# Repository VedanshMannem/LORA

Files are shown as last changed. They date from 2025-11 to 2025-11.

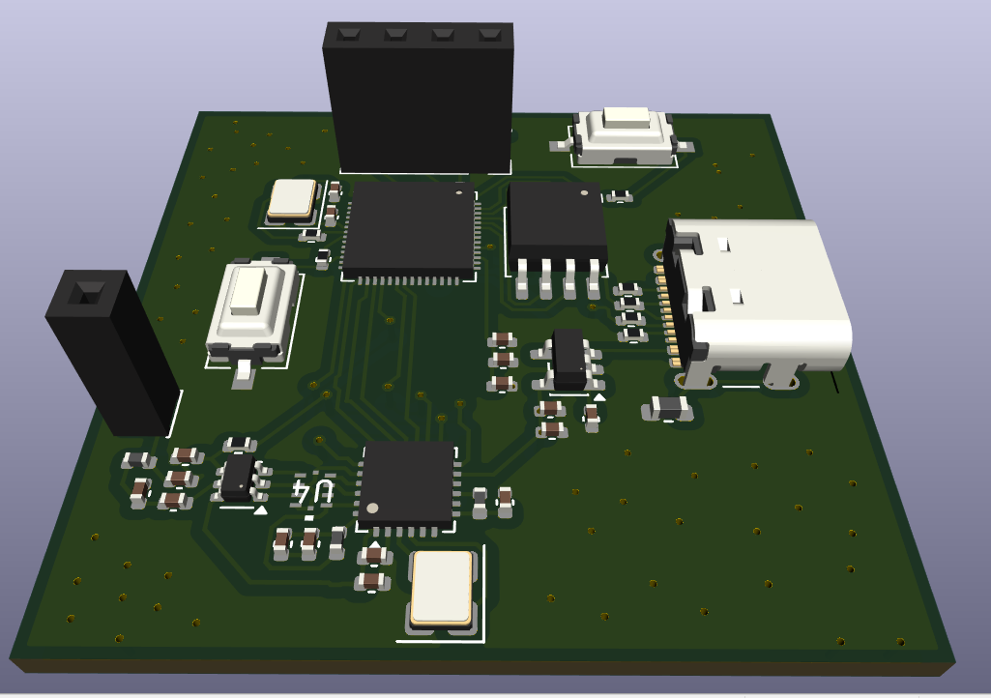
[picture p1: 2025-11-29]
photos/Screenshot 2025-11-29 044827.png

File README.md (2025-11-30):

# LoRa puck
This project's goal is to make my own LoRa (long rage) puck. It can transmit RF (radio frequency) signals and this board also comes with a 4 pin connector to attach outside sensors. The ultimate purpose of this board is to learn more about RF circuits and logic as well as create a module for transmission. 

## Some takeaways
This is one of my first full scale PCB projects. I found this one extremely fun because I got to learn a lot more about RF circuits, some of the physics behind managing these electronics, and it was just great practice overall to improve my schematics and PCB routing. This was also my first time working with multi-layer PCBs, and the whole via concept was really cool to connect gnd across different layers. Until now, this has definitely been my best hardware project!

## Usage
This repo contains KiCAD project files as well as photos showing the finished project (schematics, 2D & 3D layout JLCPCB final version, etc.). The included BOM contains a full cost breakdown of all necessary components. Some components aren't in stock currently, so a few subsitutes were used. A lot of them also require extended assembly, slightly increasing the cost of the PCB. I have a few substitutes to my BOM already listed, but I think it's price optimized especially considering all the specific modules required for this project. 

## Some photos:




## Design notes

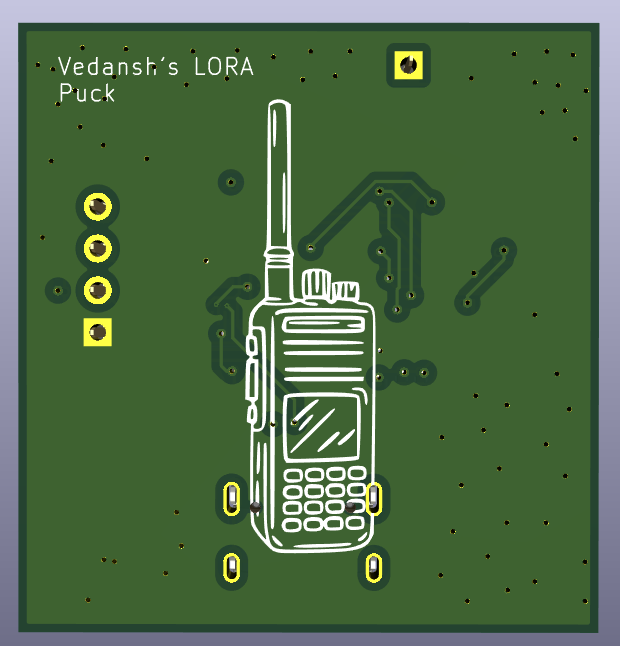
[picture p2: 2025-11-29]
photos/Screenshot 2025-11-29 053127.png

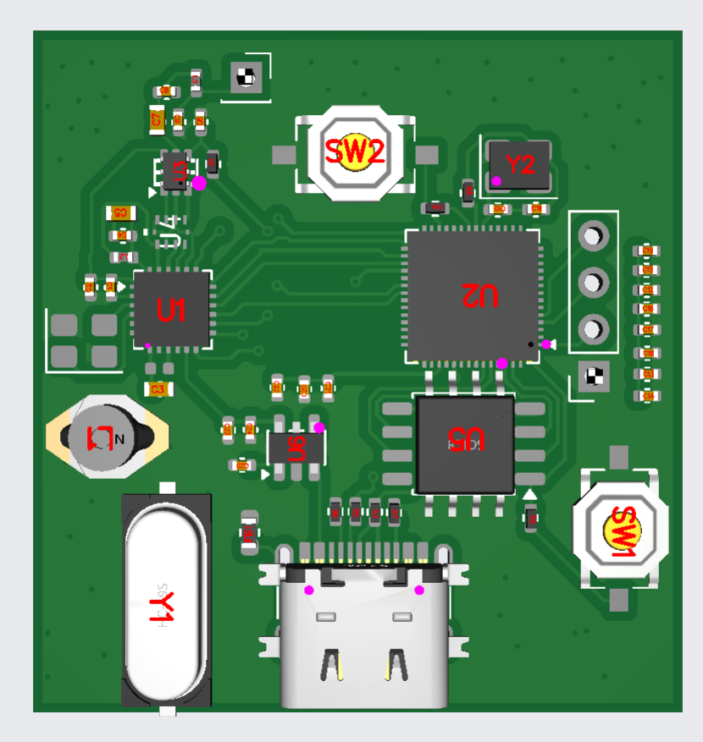
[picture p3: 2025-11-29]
photos/Screenshot 2025-11-29 154054.png

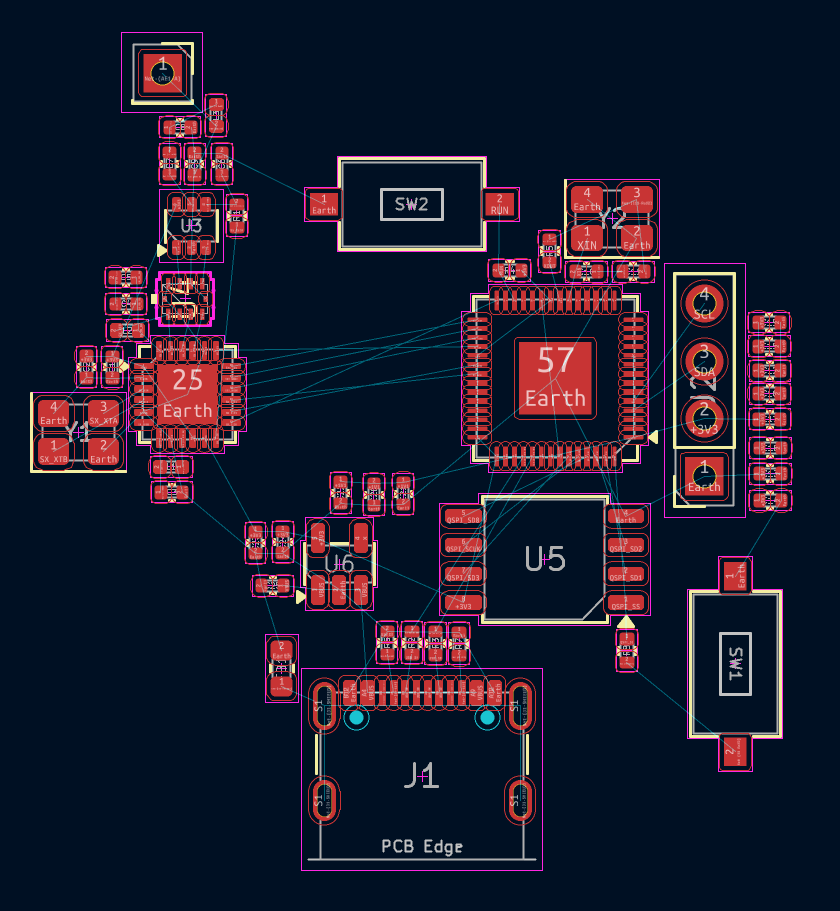
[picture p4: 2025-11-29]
photos/Screenshot 2025-11-29 034014.png

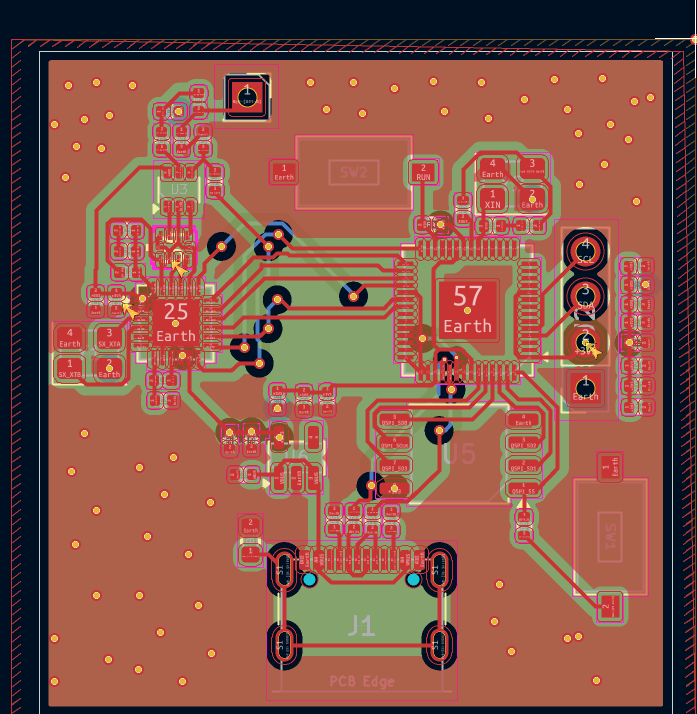
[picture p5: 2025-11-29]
photos/Screenshot 2025-11-29 044521.png

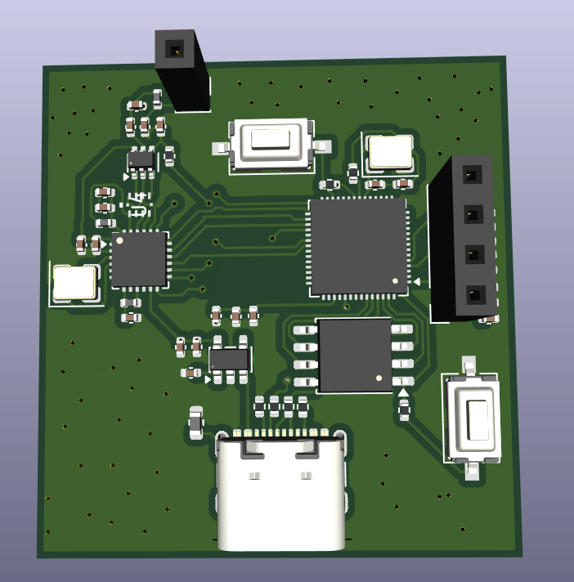
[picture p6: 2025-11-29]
photos/Screenshot 2025-11-29 045448.png

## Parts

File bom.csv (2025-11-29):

Part Number | Description | Qty | Total Price | Link
C10852 | 4*4*1.7 贴片 (Tact Switch) | 5 | 0.1035 | https://lcsc.com/search?q=C10852
C23380830 | AP2112K-3.3TRG1 | 5 | 0.4405 | https://lcsc.com/search?q=C23380830
C25744 | 0402WGF1002TCE | 2 | 0.0012 | https://lcsc.com/search?q=C25744
C1622 | CL10B473KB8NNNC | 2 | 0.0106 | https://lcsc.com/search?q=C1622
C18077642 | BX-TYPE-C-MWT16P | 7 | 1.6695 | https://lcsc.com/search?q=C18077642
C2831497 | 434MHz-SMA Flexible antenna | 2 | 3.615 | https://lcsc.com/search?q=C2831497
C9002 | X322512MSB4SI | 2 | 0.129 | https://lcsc.com/search?q=C9002
C25076 | 0402WGF1000TCE | 2 | 0.001 | https://lcsc.com/search?q=C25076
C14709 | BLM18PG121SN1D | 2 | 0.012 | https://lcsc.com/search?q=C14709
C49569550 | 2011-1X04G00LB | 2 | 0.0426 | https://lcsc.com/search?q=C49569550
C2040 | RP2040 | 2 | 1.833 | https://lcsc.com/search?q=C2040
C329840 | SDT0402T-150M-N | 5 | 1.7925 | https://lcsc.com/search?q=C329840
C131025 | W25Q16JVSSIQ | 2 | 1.11 | https://lcsc.com/search?q=C131025
C97998 | LQG15HS47NJ02D | 20 | 0.152 | https://lcsc.com/search?q=C97998
C1567 | 0402CG470J500NT | 2 | 0.002 | https://lcsc.com/search?q=C1567
C274349 | RC0402FR-0727R4L | 20 | 0.008 | https://lcsc.com/search?q=C274349
C1565 | 0402CG3R3C500NT | 20 | 0.02 | https://lcsc.com/search?q=C1565
C1623 | CL10B474KA8NNNC | 2 | 0.014 | https://lcsc.com/search?q=C1623
C15525 | CL05A106MQ5NUNC | 4 | 0.018 | https://lcsc.com/search?q=C15525
C52923 | CL05A105KA5NQNC | 4 | 0.0116 | https://lcsc.com/search?q=C52923
C12674 | X49SM8MSD2SC | 2 | 0.1704 | https://lcsc.com/search?q=C12674
C1548 | 0402CG150J500NT | 4 | 0.004 | https://lcsc.com/search?q=C1548
C11702 | 0402WGF1001TCE | 4 | 0.0024 | https://lcsc.com/search?q=C11702
C162547 | LQG15HS9N1J02D | 20 | 0.118 | https://lcsc.com/search?q=C162547
C1525 | CL05B104KO5NNNC | 24 | 0.0288 | https://lcsc.com/search?q=C1525
C25905 | 0402WGF5101TCE | 4 | 0.002 | https://lcsc.com/search?q=C25905
C1523 | 0402B102K500NT | 2 | 0.0022 | https://lcsc.com/search?q=C1523
C191341 | SX1262IMLTRT | 2 | 6.204 | https://lcsc.com/search?q=C191341
C47117600 | TPE4259-63 | 5 | 0.6805 | https://lcsc.com/search?q=C47117600
C1619 | 0603B393K500NT | 20 | 0.076 | https://lcsc.com/search?q=C1619

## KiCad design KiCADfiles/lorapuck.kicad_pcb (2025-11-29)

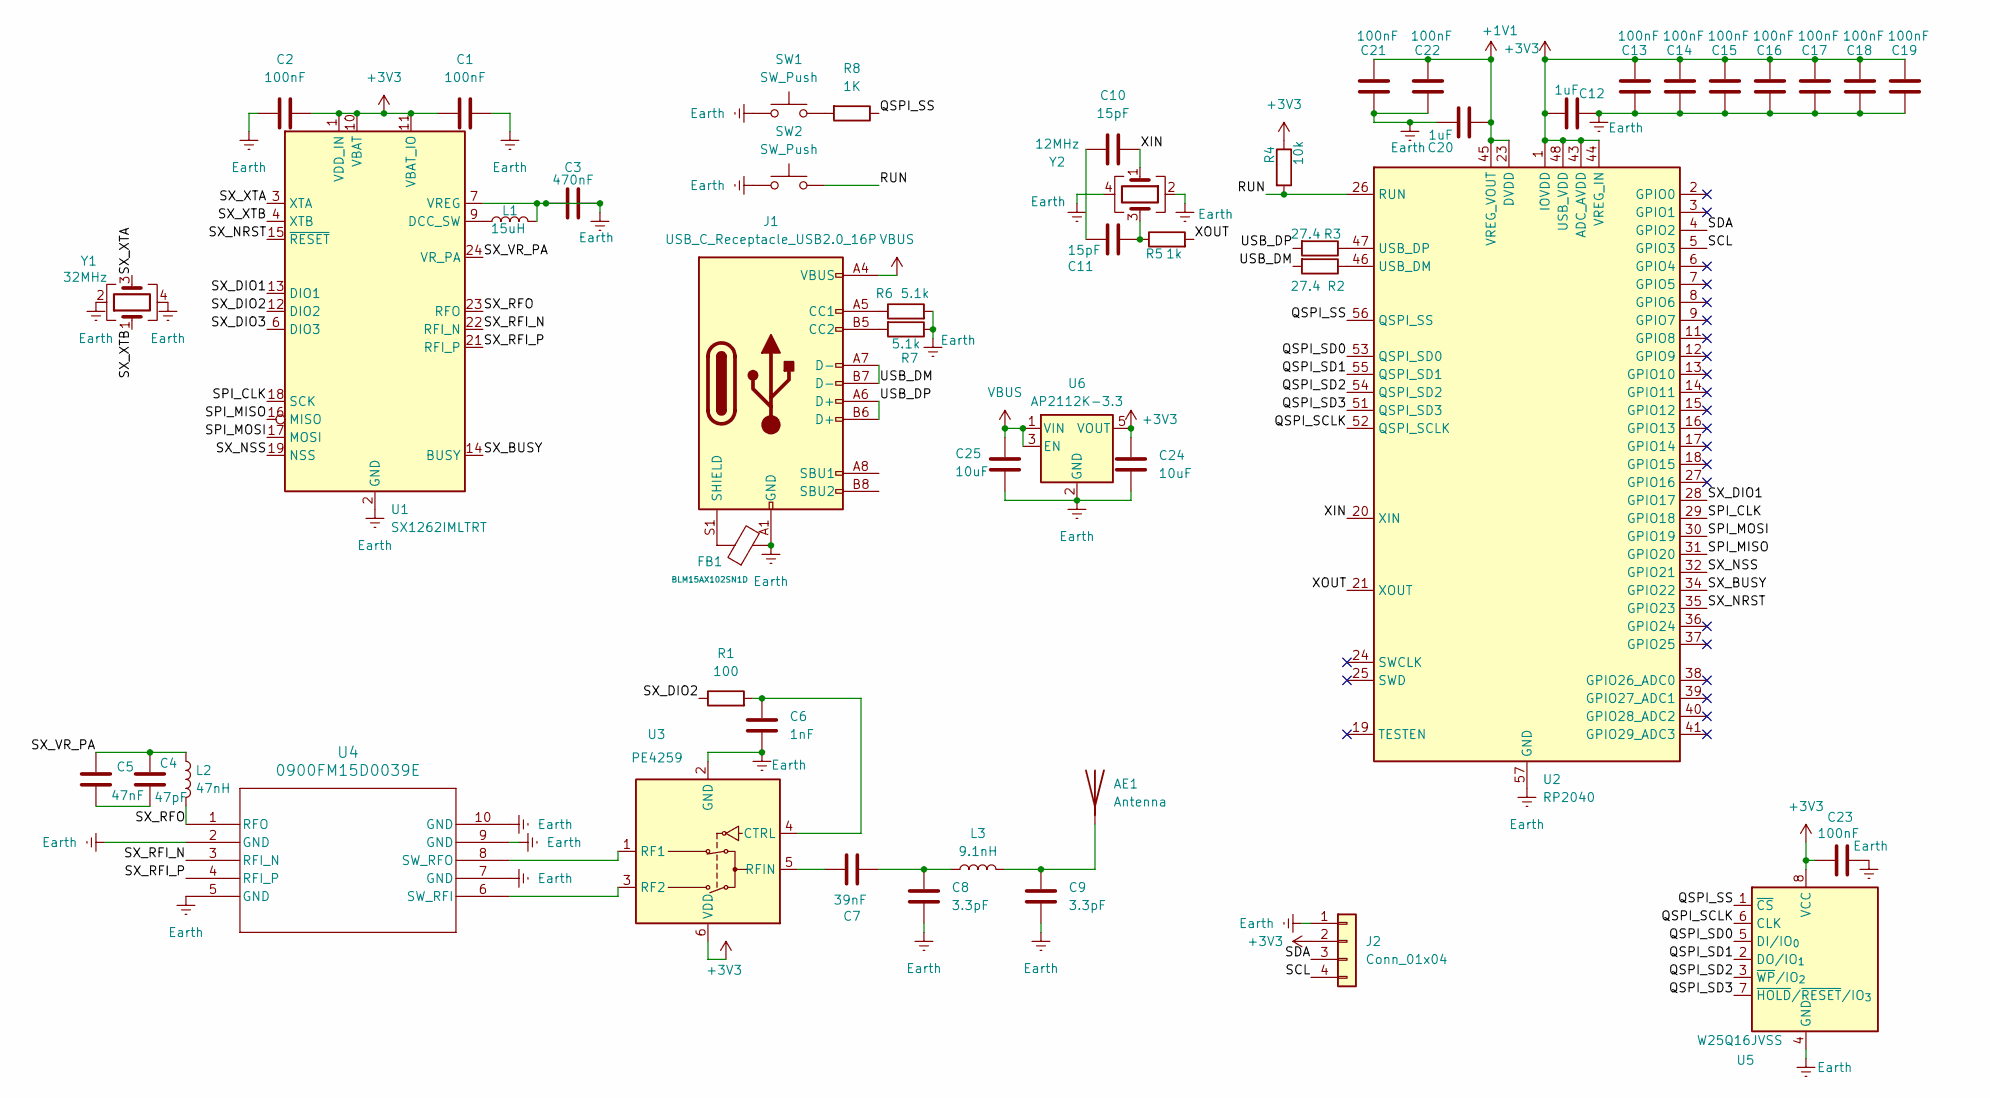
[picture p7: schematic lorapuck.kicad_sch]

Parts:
AE1: Antenna; PinSocket_1x01_P2.54mm_Vertical
C1, C2, C13, C14, C15, C16, C17, C18, C19, C21, C22, C23: 100nF; C_0402_1005Metric
C3: 470nF; C_0402_1005Metric
C4: 47pF; C_0402_1005Metric
C5: 47nF; C_0402_1005Metric
C6: 1nF; C_0402_1005Metric
C7: 39nF; C_0402_1005Metric
C8, C9: 3.3pF; C_0402_1005Metric
C10, C11: 15pF; C_0402_1005Metric
C12, C20: 1uF; C_0402_1005Metric
C24, C25: 10uF; C_0402_1005Metric
FB1: BLM15AX102SN1D; FB_0603; Current Rating 2A; Tolerance ±25%; Part BLM18PG121SN1D; LCSC C14709
J1: USB_C_Receptacle_USB2.0_16P; USB_C_Receptacle_GCT_USB4105-xx-A_16P_TopMnt_Horizontal
J2: Conn_01x04; PinSocket_1x04_P2.54mm_Vertical
L1: 15uH; L_0402_1005Metric
L2: 47nH; L_0402_1005Metric
L3: 9.1nH; L_0402_1005Metric
R1: 100; R_0402_1005Metric
R2, R3: 27.4; R_0402_1005Metric
R4: 10k; R_0402_1005Metric
R5: 1k; R_0402_1005Metric
R6, R7: 5.1k; R_0402_1005Metric
R8: 1K; R_0402_1005Metric
SW1, SW2: SW_Push; SW_Tactile_SPST_NO_Straight_CK_PTS636Sx25SMTRLFS
U1: SX1262IMLTRT; QFN-24-1EP_4x4mm_P0.5mm_EP2.6x2.6mm
U2: RP2040; QFN-56-1EP_7x7mm_P0.4mm_EP3.2x3.2mm
U3: PE4259; SOT-363_SC-70-6
U4: 0900FM15D0039E; 0900FM15D0039E_JOT
U5: W25Q16JVSS; SOIC-8_5.3x5.3mm_P1.27mm
U6: AP2112K-3.3; SOT-23-5
Y1: 32MHz; Crystal_SMD_3225-4Pin_3.2x2.5mm
Y2: 12MHz; Crystal_SMD_Abracon_ABM8G-4Pin_3.2x2.5mm

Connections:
+1V1: C20.2, C21.1, C22.1, U2.23 (DVDD), U2.45 (VREG_VOUT), U2.50 (DVDD)
+3V3: C1.1, C2.2, C12.1, C13.1, C14.1, C15.1, C16.1, C17.1, C18.1, C19.1, C23.1, C24.1, J2.2, R4.1, U1.1 (VDD_IN), U1.10 (VBAT), U1.11 (VBAT_IO), U2.1 (IOVDD), U2.10 (IOVDD), U2.22 (IOVDD), U2.33 (IOVDD), U2.42 (IOVDD), U2.43 (ADC_AVDD), U2.44 (VREG_IN), U2.48 (USB_VDD), U2.49 (IOVDD), U3.6 (VDD), U5.8 (VCC), U6.5 (VOUT)
/QSPI_SCLK: U2.52 (QSPI_SCLK), U5.6 (CLK)
/QSPI_SD0: U2.53 (QSPI_SD0), U5.5 (DI/IO_{0})
/QSPI_SD1: U2.55 (QSPI_SD1), U5.2 (DO/IO_{1})
/QSPI_SD2: U2.54 (QSPI_SD2), U5.3 (~WP/IO_{2})
/QSPI_SD3: U2.51 (QSPI_SD3), U5.7 (~HOLD/~RESET/IO_{3})
/QSPI_SS: R8.1, U2.56 (QSPI_SS), U5.1 (~CS)
/RUN: R4.2, SW2.2, U2.26 (RUN)
/SCL: J2.4, U2.5 (GPIO3)
/SDA: J2.3, U2.4 (GPIO2)
/SPI_CLK: U1.18 (SCK), U2.29 (GPIO18)
/SPI_MISO: U1.16 (MISO), U2.31 (GPIO20)
/SPI_MOSI: U1.17 (MOSI), U2.30 (GPIO19)
/SX_BUSY: U1.14 (BUSY), U2.34 (GPIO22)
/SX_DIO1: U1.13 (DIO1), U2.28 (GPIO17)
/SX_DIO2: R1.1, U1.12 (DIO2)
/SX_DIO3: U1.6 (DIO3)
/SX_NRST: U1.15 (~RESET), U2.35 (GPIO23)
/SX_NSS: U1.19 (NSS), U2.32 (GPIO21)
/SX_RFI_N: U1.22 (RFI_N), U4.3 (RFI_N)
/SX_RFI_P: U1.21 (RFI_P), U4.4 (RFI_P)
/SX_RFO: L2.2, U1.23 (RFO), U4.1 (RFO)
/SX_VR_PA: C4.1, C5.1, L2.1, U1.24 (VR_PA)
/SX_XTA: U1.3 (XTA), Y1.3
/SX_XTB: U1.4 (XTB), Y1.1
/USB_DM: J1.A7 (D-), J1.B7 (D-), R2.2
/USB_DP: J1.A6 (D+), J1.B6 (D+), R3.2
/XIN: C10.2, U2.20 (XIN), Y2.1
/XOUT: R5.2, U2.21 (XOUT)
unnamed: AE1.1 (A), C9.1, L3.2
unnamed: C4.2, C5.2
unnamed: C7.2, C8.1, L3.1
unnamed: C10.1, C11.1
unnamed: C11.2, R5.1, Y2.3
unnamed: J1.A5 (CC1), R6.1
unnamed: J1.B5 (CC2), R7.2
unnamed: FB1.1, J1.S1 (SHIELD)
unnamed: R8.2, SW1.2
unnamed: L1.1, U1.9 (DCC_SW)
unnamed: R2.1, U2.46 (USB_DM)
unnamed: R3.1, U2.47 (USB_DP)
unnamed: C6.1, R1.2, U3.4 (CTRL)
unnamed: U3.1 (RF1), U4.8 (SW_RFO)
unnamed: U3.3 (RF2), U4.6 (SW_RFI)
unnamed: C7.1, U3.5 (RFIN)
VBUS: C25.1, J1.A4 (VBUS), J1.A9 (VBUS), J1.B4 (VBUS), J1.B9 (VBUS), U6.1 (VIN), U6.3 (EN)

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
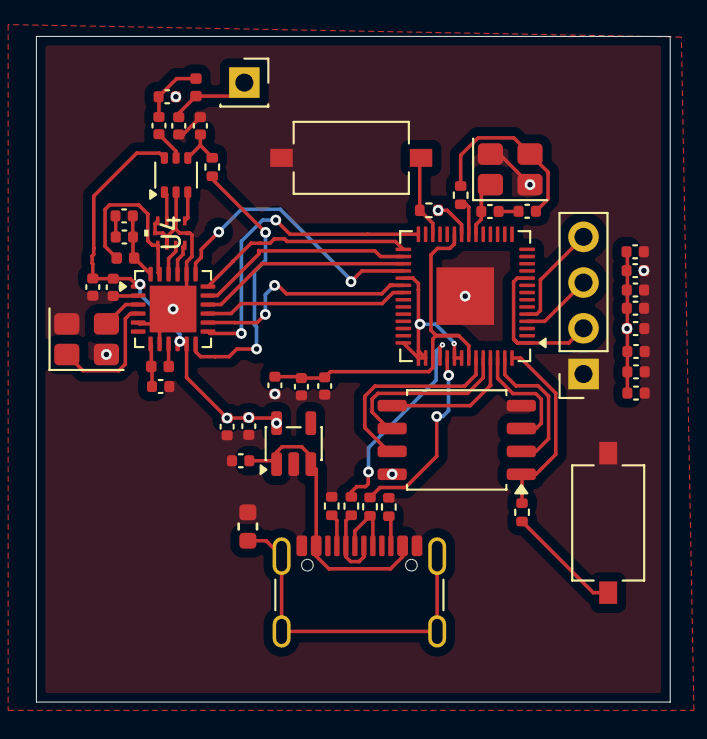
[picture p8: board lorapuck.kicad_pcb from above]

Board: 4 copper layers, 35.2 x 37.0 mm, 50 parts (0 on the bottom side), 48 nets.

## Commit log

2025-11-29 kicad files
    [lorapuck.kicad_pcb, lorapuck.kicad_sch]
2025-11-30 Enhance usage section with BOM details and substitutes
    Expanded the usage section to include information about BOM substitutes and cost optimization.
